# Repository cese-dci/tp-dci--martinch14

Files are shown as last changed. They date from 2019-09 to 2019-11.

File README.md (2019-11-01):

Repositorio de la materia Diseño de Circuitos Integrados de la Carrera de Especialización en Sistemas Embebidos UBA

El siguiente diseño incluye el circuito integrado TMC5130 de la empresa TRINAMIC para el manejo de motores paso a paso
conectado con el módulo del microcontrolador ESP32

Martin Abel Gambarotta
8vo Cohorte

View 3D

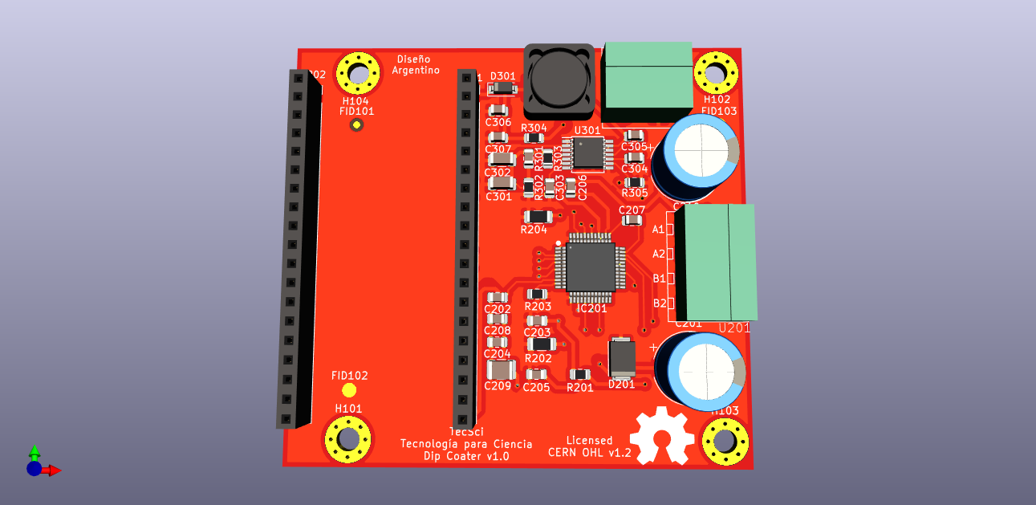
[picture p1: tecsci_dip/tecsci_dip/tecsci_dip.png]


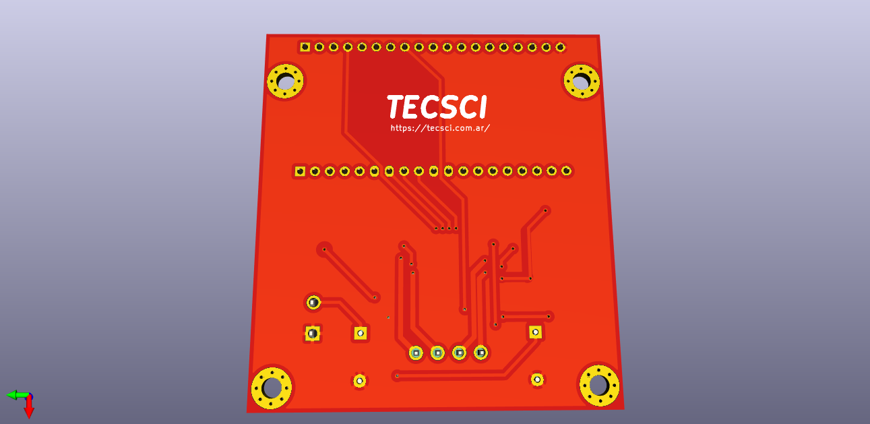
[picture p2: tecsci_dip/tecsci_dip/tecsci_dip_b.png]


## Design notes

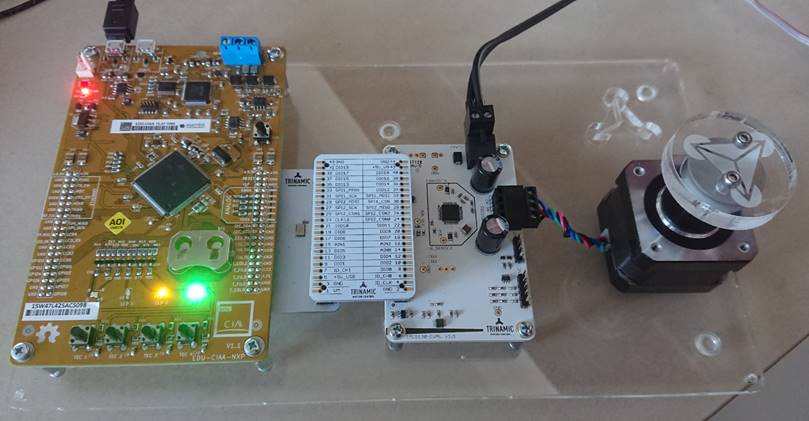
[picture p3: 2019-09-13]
info_propuesta/educiaa+tmc5130.jpg

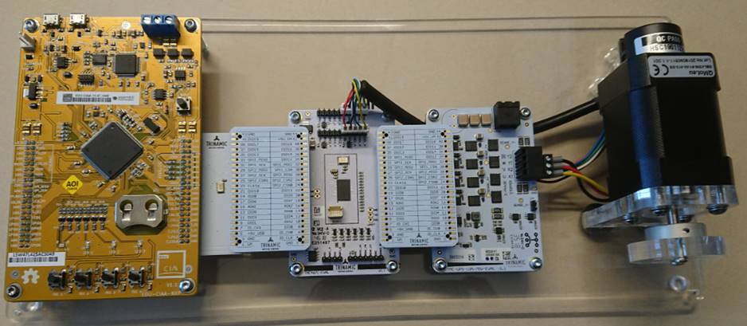
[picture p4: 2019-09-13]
info_propuesta/educiaa+tmc4671.jpg

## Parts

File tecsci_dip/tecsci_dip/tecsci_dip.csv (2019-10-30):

Id | Designator | Package | Quantity | Designation | Supplier and ref
1 | C201,C210 | CP_Radial_D10.0mm_P7.50mm | 2 | 100uF
2 | FID103,FID102,FID101 | Fiducial_1mm_Mask2mm | 3 | Fiducial
3 | R201 | R_0805_2012Metric | 1 | 2R2
4 | C304 | C_0805_2012Metric | 1 | 1uF
5 | U301 | TSSOP-14-1EP_4.4x5mm_P0.65mm | 1 | Regulador_LM5161
6 | C302 | C_1206_3216Metric | 1 | 100nF
7 | R305 | R_0805_2012Metric | 1 | 2.2k
8 | H104,H103,H102,H101 | MountingHole_3.2mm_M3_Pad_Via | 4 | MountingHole
9 | OSHWA101 | OSHW-Symbol_8.9x8mm_SilkScreen | 1 | Logo_Open_Hardware_Small
10 | IC201 | QFP50P900X900X113-49N_NOFID | 1 | TMC5130
11 | R203 | R_0805_2012Metric | 1 | 0R
12 | R202,R204 | R_1206_3216Metric | 2 | 0R15/0.5W
13 | C209 | C_1210_3225Metric | 1 | 4.7uF
14 | R304 | R_0805_2012Metric | 1 | 3.3k
15 | R302 | R_0805_2012Metric | 1 | 6.8k
16 | C305 | C_0805_2012Metric | 1 | 10nF
17 | C303,C207 | C_0805_2012Metric | 2 | 22nF
18 | C208,C206,C204,C202 | C_0805_2012Metric | 4 | 100nF
19 | C205 | C_0805_2012Metric | 1 | 4.7uF
20 | C203 | C_0805_2012Metric | 1 | 470nF
21 | D301 | D_SOD-123 | 1 | PMEG6010CEH
22 | U201 | AKL169_04_POL | 1 | AKL182_04_POL_HEADER
23 | R303 | R_0805_2012Metric | 1 | 150k
24 | R301 | C_0805_2012Metric | 1 | 30k
25 | POWER_IN301 | AKL349_02_POL | 1 | POL_HEADER
26 | L301 | L_Bourns-SRU8043 | 1 | SRU8043
27 | J202,J201 | PinSocket_1x19_P2.54mm_Vertical | 2 | Conn_01x19_ESP32
28 | D201 | SMB | 1 | SMBJ43A
29 | C307,C306 | C_0805_2012Metric | 2 | 10uF
30 | C301 | C_1206_3216Metric | 1 | 2.2uF

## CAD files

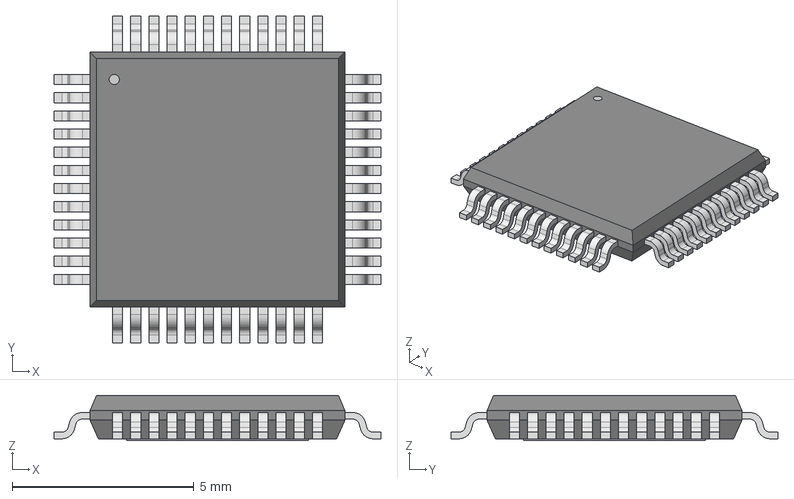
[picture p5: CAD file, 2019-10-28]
tecsci_dip/tecsci_dip/modelos3D/TMC5130eTQFP48_9x9.step
8.99 x 8.99 x 1.25 mm

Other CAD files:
tecsci_dip/tecsci_dip/modelos3D/TMC5130eTQFP48_9x9-L.step
tecsci_dip/tecsci_dip/modelos3D/TMC5130eTQFP48_9x9-M.step

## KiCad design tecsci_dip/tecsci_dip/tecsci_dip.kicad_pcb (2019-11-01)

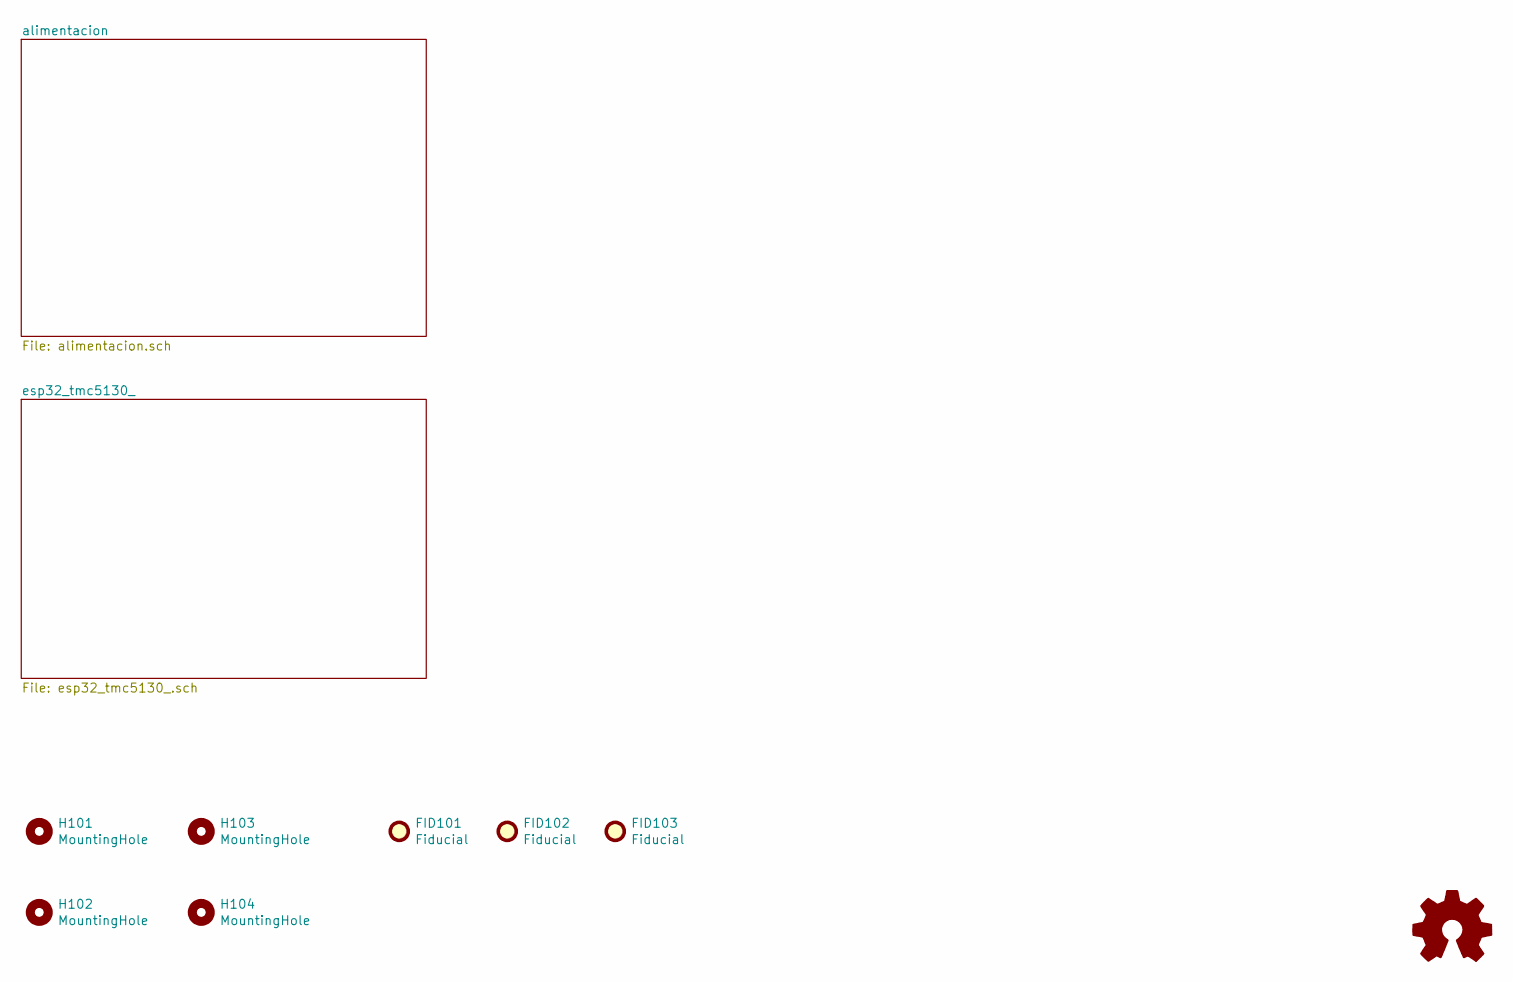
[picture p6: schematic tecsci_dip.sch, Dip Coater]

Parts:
FID101, FID102, FID103: Fiducial; Fiducial_1mm_Mask2mm
H101, H102, H103, H104: MountingHole; MountingHole_3.2mm_M3_Pad_Via
OSHWA101: Logo_Open_Hardware_Small; OSHW-Symbol_8.9x8mm_SilkScreen

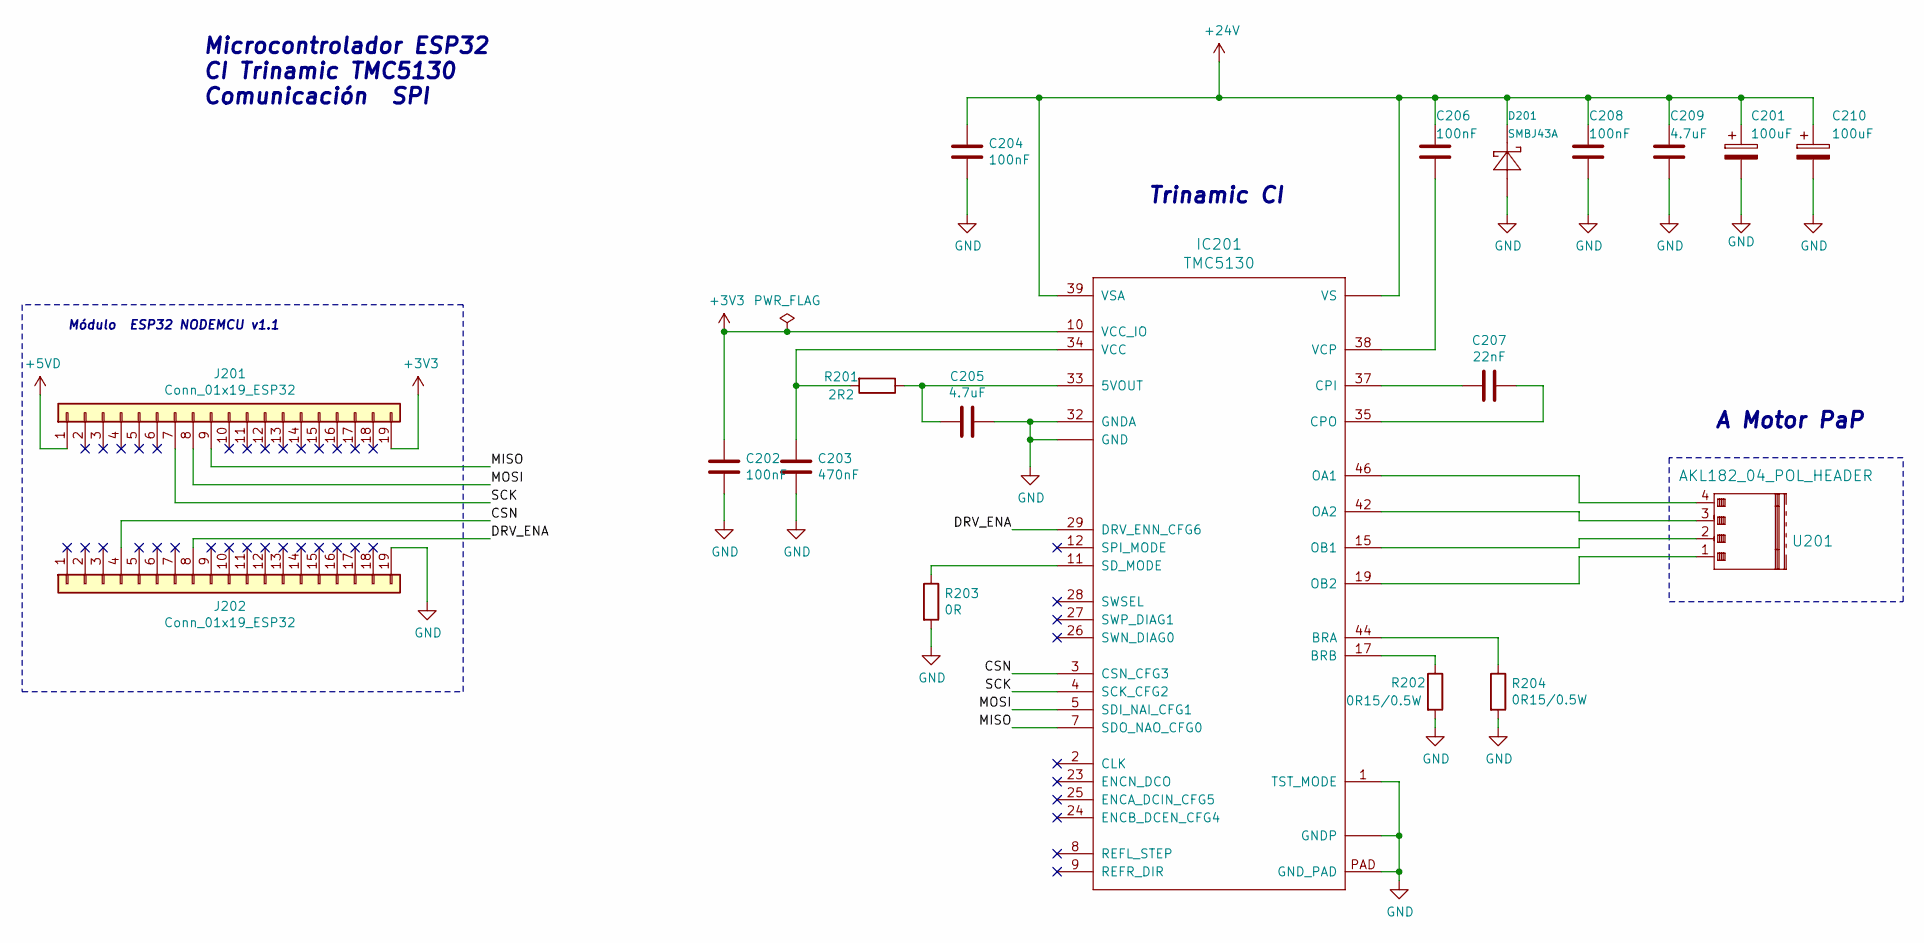
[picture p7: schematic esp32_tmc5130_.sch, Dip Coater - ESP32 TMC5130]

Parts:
C201, C210: 100uF; CP_Radial_D10.0mm_P7.50mm
C202, C204, C206, C208: 100nF; C_0805_2012Metric
C203: 470nF; C_0805_2012Metric
C205: 4.7uF; C_0805_2012Metric; digikey# 399-15711-2-ND
C207: 22nF; C_0805_2012Metric
C209: 4.7uF; C_1210_3225Metric
D201: SMBJ43A; SMB; digikey# SMBJ43AFSTR-ND
IC201: TMC5130; QFP50P900X900X113-49N_NOFID; digikey# 1460-1124-ND
J201, J202: Conn_01x19_ESP32; PinSocket_1x19_P2.54mm_Vertical
R201: 2R2; R_0805_2012Metric
R202, R204: 0R15/0.5W; R_1206_3216Metric
R203: 0R; R_0805_2012Metric
U201: AKL182_04_POL_HEADER; AKL169_04_POL

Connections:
+3V3: C202.1, IC201.10 (VCC_IO), J201.19
+5VD: J201.1; also elsewhere on the board
+24V: C201.1, C204.1, C206.1, C208.1, C209.1, C210.1, D201.C, IC201.21 (VS), IC201.39 (VSA), IC201.40 (VS); also elsewhere on the board
/esp32_tmc5130_/CSN: IC201.3 (CSN_CFG3), J202.4
/esp32_tmc5130_/DRV_ENA: IC201.29 (DRV_ENN_CFG6), J202.8
/esp32_tmc5130_/MISO: IC201.7 (SDO_NAO_CFG0), J201.9
/esp32_tmc5130_/MOSI: IC201.5 (SDI_NAI_CFG1), J201.8
/esp32_tmc5130_/SCK: IC201.4 (SCK_CFG2), J201.7
GND: C201.2, C202.2, C203.2, C204.2, C205.1, C208.2, C209.2, C210.2, D201.A, IC201.1 (TST_MODE), IC201.6 (GND), IC201.13 (GNDP), IC201.31 (GND), IC201.32 (GNDA), IC201.36 (GND), IC201.48 (GNDP), IC201.PAD (GND_PAD), J202.19, R202.2, R203.2, R204.2; also elsewhere on the board
unnamed: C203.1, IC201.34 (VCC), R201.2
unnamed: C205.2, IC201.33 (5VOUT), R201.1
unnamed: C206.2, IC201.38 (VCP)
unnamed: C207.1, IC201.35 (CPO)
unnamed: C207.2, IC201.37 (CPI)
unnamed: IC201.11 (SD_MODE), R203.1
unnamed: IC201.15 (OB1), U201.2
unnamed: IC201.17 (BRB), R202.1
unnamed: IC201.19 (OB2), U201.1
unnamed: IC201.42 (OA2), U201.3
unnamed: IC201.44 (BRA), R204.1
unnamed: IC201.46 (OA1), U201.4

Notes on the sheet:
Módulo ESP32 NODEMCU v1.1
Trinamic CI
A Motor PaP
Microcontrolador ESP32 CI Trinamic TMC5130 Comunicación SPI

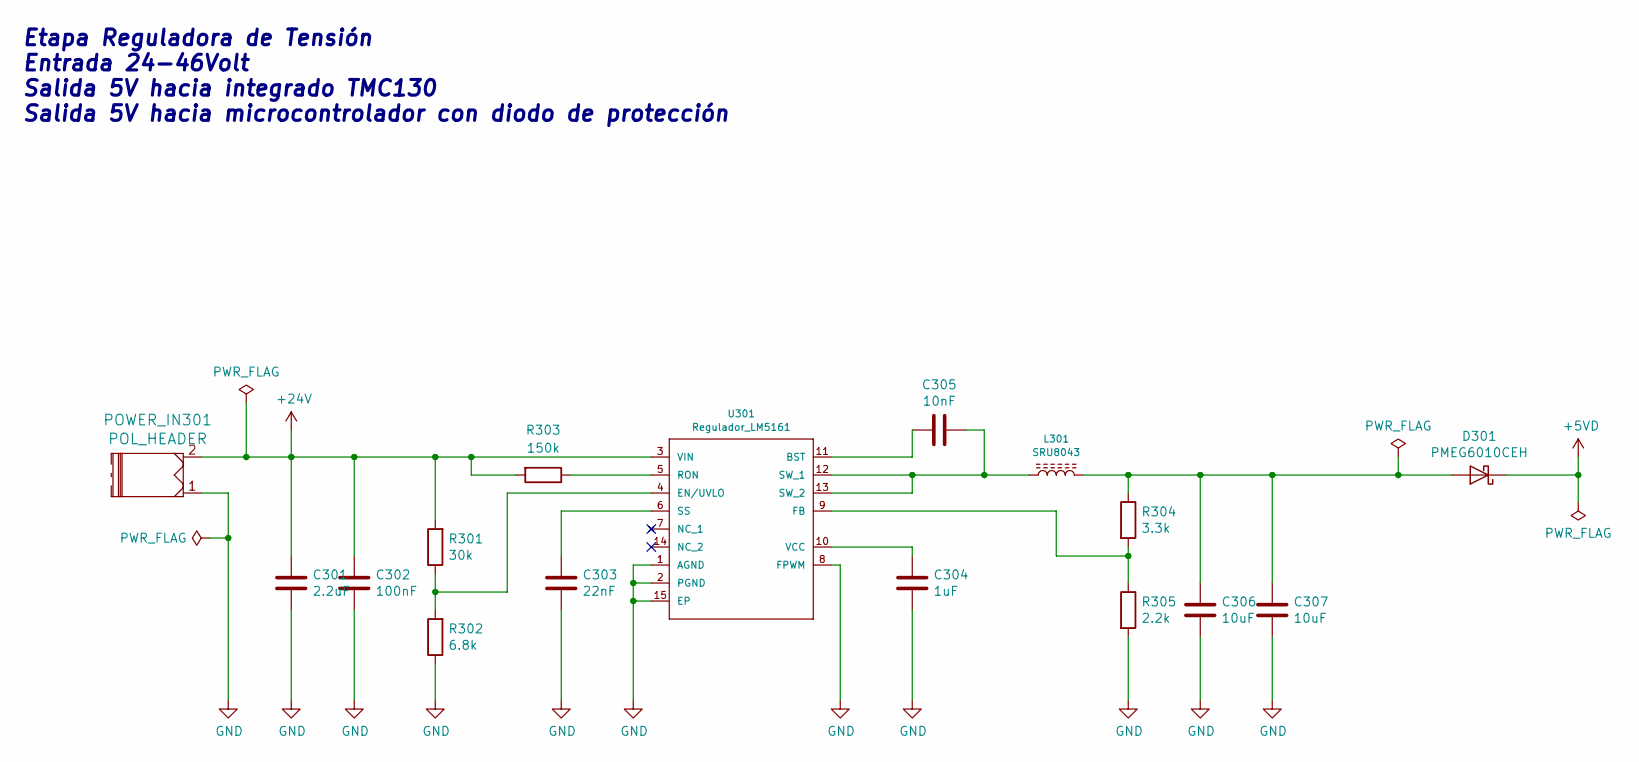
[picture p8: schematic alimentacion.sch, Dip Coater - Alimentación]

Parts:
C301: 2.2uF; C_1206_3216Metric
C302: 100nF; C_1206_3216Metric
C303: 22nF; C_0805_2012Metric
C304: 1uF; C_0805_2012Metric
C305: 10nF; C_0805_2012Metric
C306, C307: 10uF; C_0805_2012Metric
D301: PMEG6010CEH; D_SOD-123; digikey# 1727-3848-2-ND
L301: SRU8043; L_Bourns-SRU8043; digikey# SRU8043-100YTR-ND
POWER_IN301: POL_HEADER; AKL349_02_POL
R301: 30k; C_0805_2012Metric
R302: 6.8k; R_0805_2012Metric
R303: 150k; R_0805_2012Metric
R304: 3.3k; R_0805_2012Metric
R305: 2.2k; R_0805_2012Metric
U301: Regulador_LM5161; TSSOP-14-1EP_4.4x5mm_P0.65mm; digikey# 296-47791-2-ND

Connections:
+5VD: D301.1 (K); also elsewhere on the board
+24V: C301.1, C302.1, POWER_IN301.2, R301.2, R303.2, U301.3 (VIN); also elsewhere on the board
GND: C301.2, C302.2, C303.2, C304.2, C306.2, C307.2, POWER_IN301.1, R302.1, R305.2, U301.1 (AGND), U301.2 (PGND), U301.8 (FPWM), U301.15 (EP); also elsewhere on the board
unnamed: C303.1, U301.6 (SS)
unnamed: C304.1, U301.10 (VCC)
unnamed: C305.1, L301.1, U301.12 (SW_1), U301.13 (SW_2)
unnamed: C305.2, U301.11 (BST)
unnamed: C306.1, C307.1, D301.2 (A), L301.2, R304.1
unnamed: R301.1, R302.2, U301.4 (EN/UVLO)
unnamed: R303.1, U301.5 (RON)
unnamed: R304.2, R305.1, U301.9 (FB)

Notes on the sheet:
Etapa Reguladora de Tensión Entrada 24-46Volt Salida 5V hacia integrado TMC130 Salida 5V hacia microcontrolador con diodo de protección

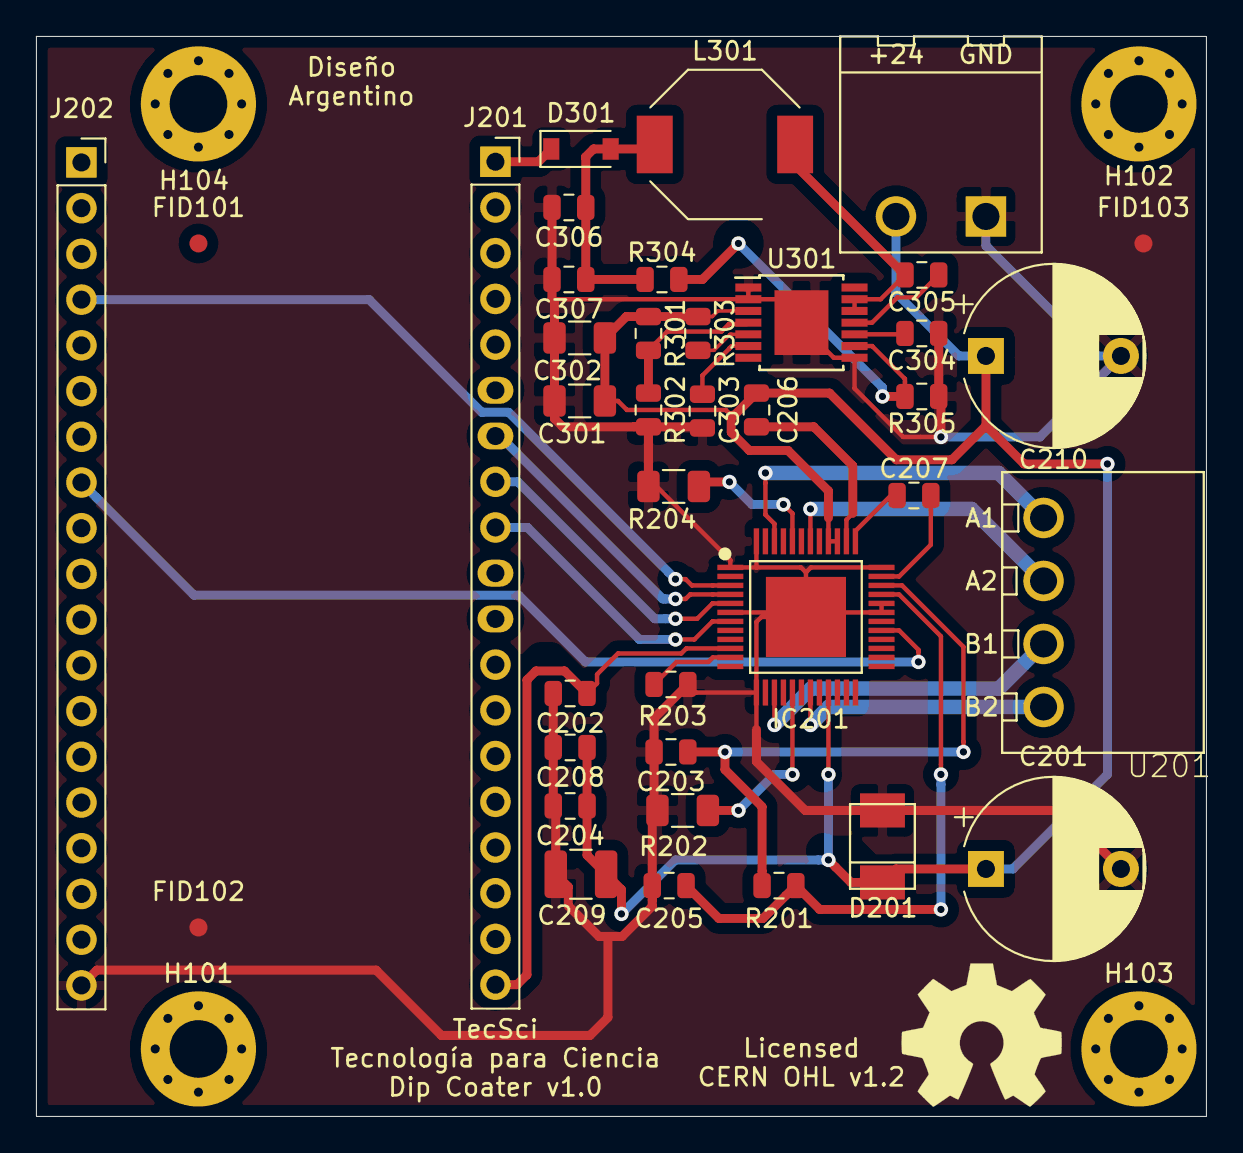
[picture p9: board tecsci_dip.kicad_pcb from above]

Board: 2 copper layers, 65.0 x 60.0 mm, 43 parts (0 on the bottom side), 29 nets.

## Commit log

2019-09-13 Add ESP32 + Trinamic TMC5130
2019-10-09 add Esquematico
    [alimentacion.sch, esp32_tmc5130.sch, esp32_tmc5130_.sch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]
2019-10-11 add value and footprint
    [alimentacion.sch, esp32_tmc5130_.sch, tecsci_dip.sch]
2019-10-11 agrego valor faltantes en esquematico
    [alimentacion.sch, esp32_tmc5130_.sch, tecsci_dip.sch]
2019-10-28 update board
    [TMC5130eTQFP48_9x9-L.step, TMC5130eTQFP48_9x9-M.step, TMC5130eTQFP48_9x9.step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]
2019-10-28 add area de cobre
    [tecsci_dip.kicad_pcb]
2019-10-28 add fiduciales
    [alimentacion.sch, tecsci_dip.kicad_pcb, tecsci_dip.sch]
2019-10-28 add license CERN OHL v.1.2
    [tecsci_dip.kicad_pcb]
2019-10-30 add correcciones compañero
    [esp32_tmc5130_.sch, tecsci_dip.csv, tecsci_dip.kicad_pcb]
2019-10-31 Se corrigen todos los errores marcados por el profesor, excepto pasar a footprint conectores de ESP32, ya que la v2 contendra al CI
    [alimentacion.sch, esp32_tmc5130_.sch, tecsci_dip.kicad_pcb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]
2019-11-01 arreglo en alimentacion.sch , habria con error en archivo
    [alimentacion.sch, tecsci_dip.kicad_pcb]

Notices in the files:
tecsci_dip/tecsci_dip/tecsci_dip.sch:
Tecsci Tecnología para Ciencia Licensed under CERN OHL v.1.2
